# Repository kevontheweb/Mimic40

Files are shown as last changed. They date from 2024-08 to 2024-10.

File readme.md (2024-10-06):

# Mimic40

A tiny ortho board that is pretending to be a fullsize. 

> I have not ordered any pcbs yet so consider these files *under development* until i can order some to test if they work.

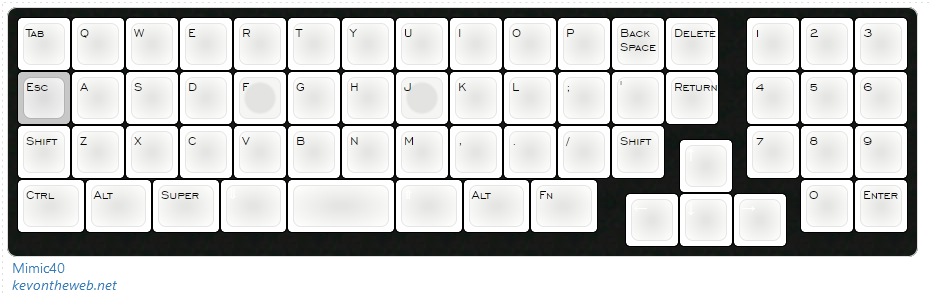
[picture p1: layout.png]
photo of the layout


<!-- ![image](https://preview.redd.it/kx884bndy0a61.jpg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) -->

## tools used to build

1. [KLE](http://www.keyboard-layout-editor.com/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'&=Return&_x:0.5%3B&=4&=5&=6%3B&@=Shift&=Z&=X&=C&=V&=B&=N&=M&=,&=.&=%2F%2F&=Shift&_x:1.5%3B&=7&=8&=9%3B&@_y:-0.75&x:12.25&t=%23ffffff%3B&=%2F&uarr%2F%3B%3B&@_y:-0.25&t=%23000000&w:1.25%3B&=Ctrl&_w:1.25%3B&=Alt&_w:1.25%3B&=Super&_t=%23ffffff&w:1.25%3B&=%2F&dArr%2F%3B&_t=%23000000&a:7&w:2%3B&=&_t=%23ffffff&a:4&w:1.25%3B&=%2F&uArr%2F%3B&_t=%23000000&w:1.25%3B&=Alt&_w:1.25%3B&=Fn&_x:3.75%3B&=0&=Enter%3B&@_y:-0.75&x:11.25&t=%23ffffff%3B&=%2F&larr%2F%3B&=%2F&darr%2F%3B&=%2F&rarr%2F)
2. [kicad](https://www.kicad.org/download/) EDA
5. [cherry mx datasheet](https://imgur.com/a/XMoHF)
<!-- x. [keyboard firmware builder](https://builder.mrkeebs.com/) for the matrix (if handwired) -->

These may be helpful for future in the design of a case

1. [builder.swillkb](builder.swillkb.com/) for the case
2. [ai03 plate generator](https://kbplate.ai03.com/)

## screenshots

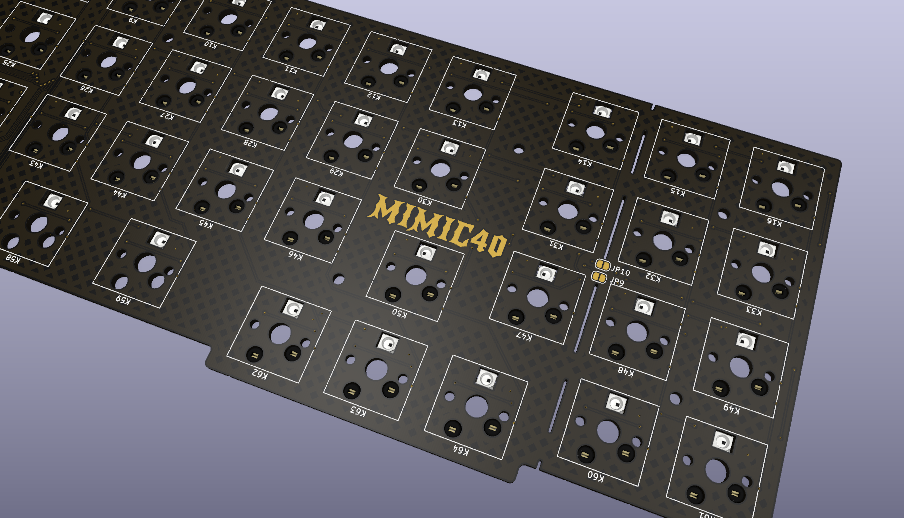
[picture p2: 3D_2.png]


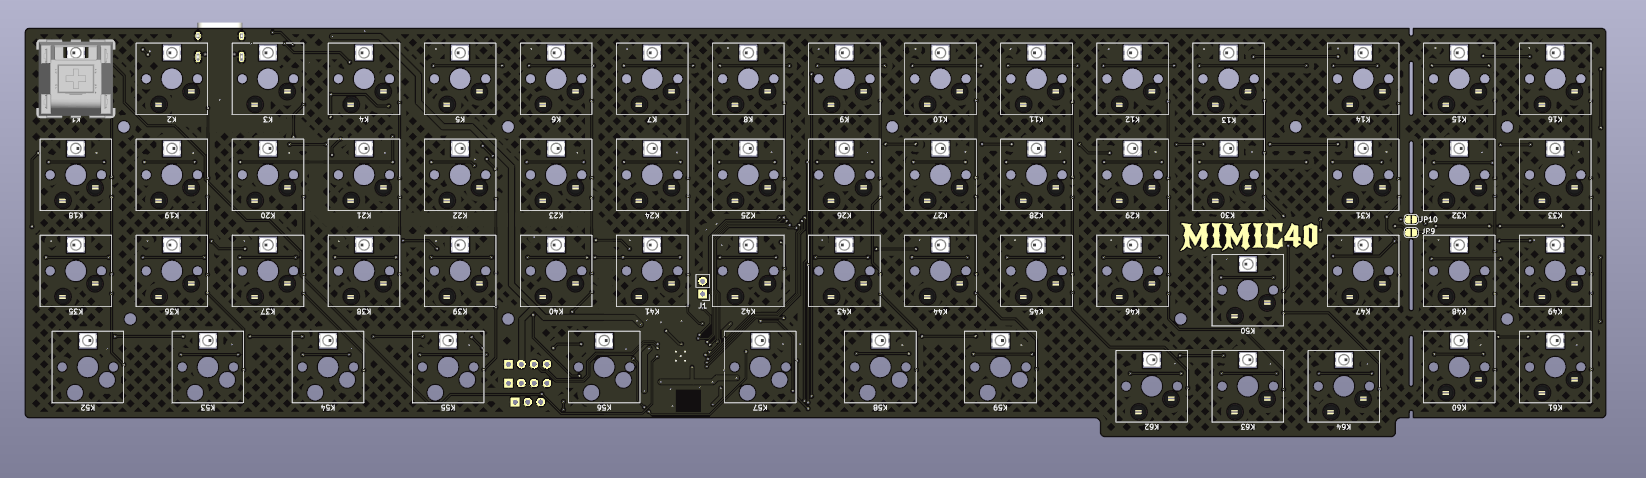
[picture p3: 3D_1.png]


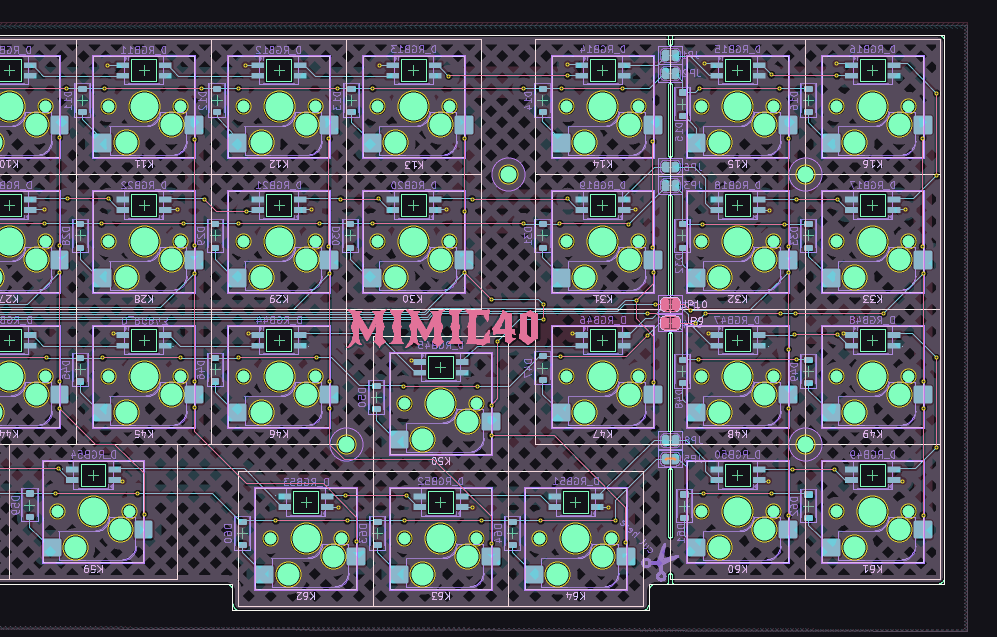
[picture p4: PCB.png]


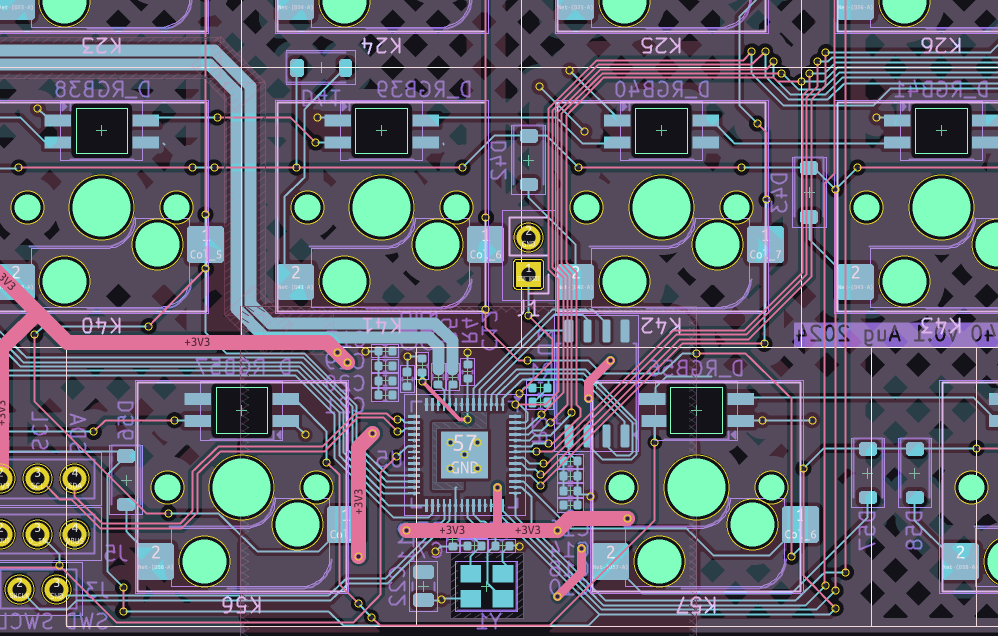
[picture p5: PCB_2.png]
photo of layout for RP2040


## references

> this was in part inspired by  [This reddit post](https://www.reddit.com/r/MechanicalKeyboards/comments/ksto32/chocolate_bar/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).

# to do

- [x] define outer geometry
- [x] per key rgb
- [x] route rows and columns
- [x] switch to rp2040 based design (no dev board)
- [x] make plate cutout file (remember to add a 2u plate mount stabiliser)
- [ ] design a case (acrlic laser cut or possible 3d printed)
- [ ] order pcbs to test
- [ ] firmware
- [ ] take it from there

## how to order

- upload gerbers
- upload bom and pos files
- confirm placements
- order missing parts elsewhere (F1 and the sockets)

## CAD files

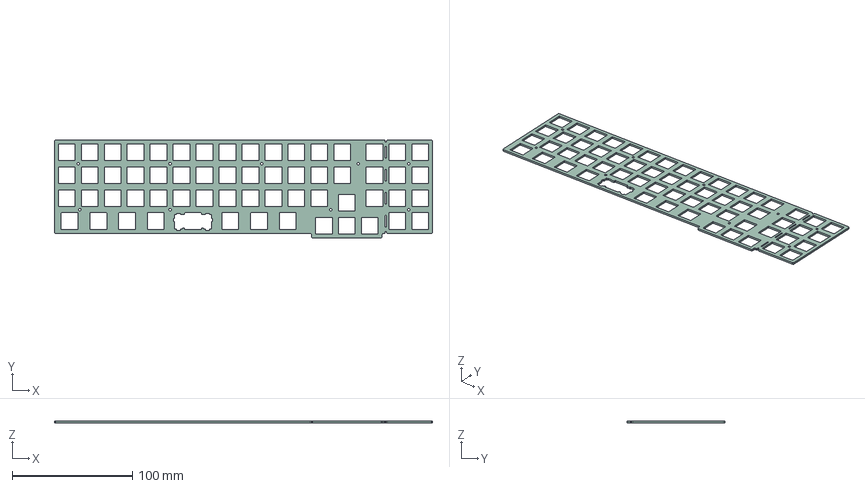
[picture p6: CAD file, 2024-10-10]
Mimic40_plate.step
313.8 x 81.2 x 1.60 mm

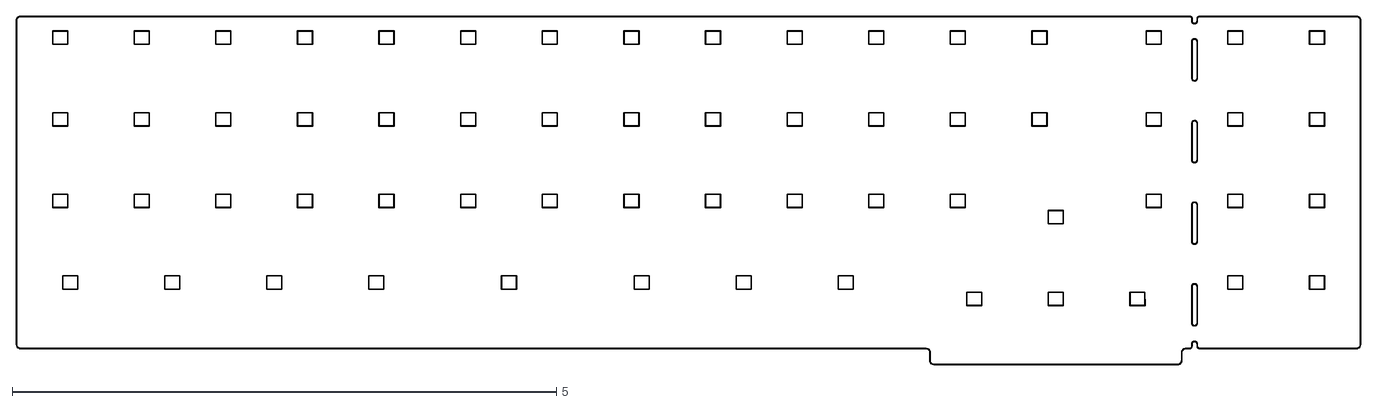
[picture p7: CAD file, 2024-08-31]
production/Mimic40_plate/Mimic40-Edge_Cuts.dxf
12.4 x 3.20

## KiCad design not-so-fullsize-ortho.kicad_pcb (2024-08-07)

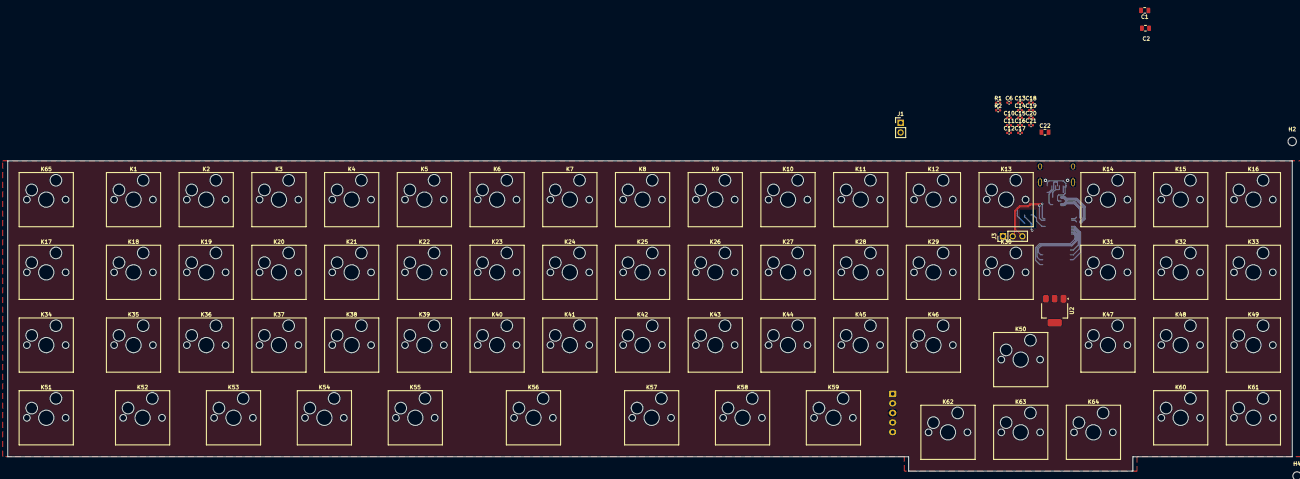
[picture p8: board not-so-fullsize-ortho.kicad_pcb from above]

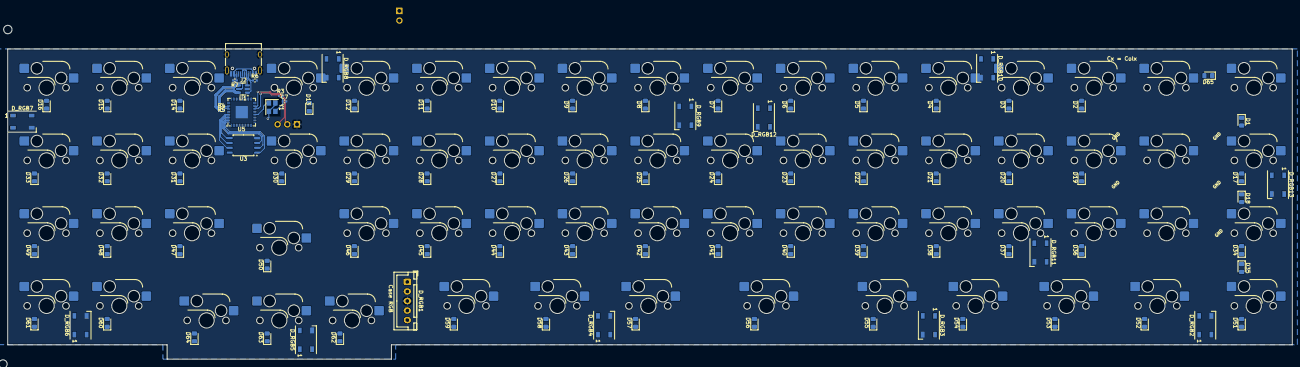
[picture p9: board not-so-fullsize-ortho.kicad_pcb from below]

Board: 2 copper layers, 336.5 x 81.2 mm, 179 parts (89 on the bottom side), 122 nets.

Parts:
C1, C2, C22: 10u; C_0805_2012Metric
C6, C7: 15p; C_0402_1005Metric
C10, C11, C12, C14, C16, C17, C18, C19, C20, C21: 100n; C_0402_1005Metric
C13, C15: 1u; C_0402_1005Metric
D1, D2, D3, D4, D5, D6, D7, D8, D9, D10, D11, D12, D13, D14, D15, D16, D17, D18, D19, D20, D21, D22, D23, D24, D25, D26, D27, D28, D29, D30, D31, D32, D33, D34, D35, D36, D37, D38, D39, D40, D41, D42, D43, D44, D45, D46, D47, D48, D49, D50, D51, D52, D53, D54, D55, D56, D57, D58, D59, D60, D61, D62, D63, D64, D65: D; D_0805_2012Metric_Pad1.15x1.40mm_HandSolder
D_RGB1: WS2812B; JST_XH_B5B-XH-A_1x05_P2.50mm_Vertical
D_RGB2, D_RGB3, D_RGB4, D_RGB5, D_RGB6, D_RGB7, D_RGB8, D_RGB9, D_RGB10, D_RGB11, D_RGB12, D_RGB13: WS2812B; LED_WS2812B_PLCC4_5.0x5.0mm_P3.2mm
H1, H2, H3, H4: MountingHole; MountingHole_2.2mm_M2
J1: Conn_01x02; PinHeader_1x02_P2.54mm_Vertical
J2: USB_C_Receptacle_USB2.0_16P; USB_C_Receptacle_HRO_TYPE-C-31-M-12
J3: Conn_01x03; PinHeader_1x03_P2.54mm_Vertical
K1: Home; SW_Hotswap_Kailh_MX_1.00u
K2: End; SW_Hotswap_Kailh_MX_1.00u
K3: Vol +; SW_Hotswap_Kailh_MX_1.00u
K4: Vol -; SW_Hotswap_Kailh_MX_1.00u
K5: Tab; SW_Hotswap_Kailh_MX_1.00u
K6: Esc; SW_Hotswap_Kailh_MX_1.00u
K7, K48: Shift; SW_Hotswap_Kailh_MX_1.00u
K8: Ctrl; SW_Hotswap_Kailh_MX_1.00u
K9: Q; SW_Hotswap_Kailh_MX_1.00u
K10: A; SW_Hotswap_Kailh_MX_1.00u
K11: Z; SW_Hotswap_Kailh_MX_1.00u
K12, K38: Alt; SW_Hotswap_Kailh_MX_1.00u
K13: W; SW_Hotswap_Kailh_MX_1.00u
K14: S; SW_Hotswap_Kailh_MX_1.00u
K15: X; SW_Hotswap_Kailh_MX_1.00u
K16: Super; SW_Hotswap_Kailh_MX_1.00u
K17: E; SW_Hotswap_Kailh_MX_1.00u
K18: D; SW_Hotswap_Kailh_MX_1.00u
K19: C; SW_Hotswap_Kailh_MX_1.00u
K20: &dArr;; SW_Hotswap_Kailh_MX_1.00u
K21: R; SW_Hotswap_Kailh_MX_1.00u
K22: F; SW_Hotswap_Kailh_MX_1.00u
K23: V; SW_Hotswap_Kailh_MX_1.00u
K24: T; SW_Hotswap_Kailh_MX_1.00u
K25: G; SW_Hotswap_Kailh_MX_1.00u
K26: B; SW_Hotswap_Kailh_MX_1.00u
K27: Blank; SW_Hotswap_Kailh_MX_1.00u
K28: Y; SW_Hotswap_Kailh_MX_1.00u
K29: H; SW_Hotswap_Kailh_MX_1.00u
K30: N; SW_Hotswap_Kailh_MX_1.00u
K31: U; SW_Hotswap_Kailh_MX_1.00u
K32: J; SW_Hotswap_Kailh_MX_1.00u
K33: M; SW_Hotswap_Kailh_MX_1.00u
K34: &uArr;; SW_Hotswap_Kailh_MX_1.00u
K35: I; SW_Hotswap_Kailh_MX_1.00u
K36: K; SW_Hotswap_Kailh_MX_1.00u
K37: ,; SW_Hotswap_Kailh_MX_1.00u
K39: O; SW_Hotswap_Kailh_MX_1.00u
K40: L; SW_Hotswap_Kailh_MX_1.00u
K41: .; SW_Hotswap_Kailh_MX_1.00u
K42: Fn; SW_Hotswap_Kailh_MX_1.00u
K43: P; SW_Hotswap_Kailh_MX_1.00u
K44: ;; SW_Hotswap_Kailh_MX_1.00u
K45: /; SW_Hotswap_Kailh_MX_1.00u
K46: Back Space; SW_Hotswap_Kailh_MX_1.00u
K47: '; SW_Hotswap_Kailh_MX_1.00u
K49: &larr;; SW_Hotswap_Kailh_MX_1.00u
K50: Delete; SW_Hotswap_Kailh_MX_1.00u
K51: Return; SW_Hotswap_Kailh_MX_1.00u
K52: &uarr;; SW_Hotswap_Kailh_MX_1.00u
K53: &darr;; SW_Hotswap_Kailh_MX_1.00u
K54: &rarr;; SW_Hotswap_Kailh_MX_1.00u
K55: 1; SW_Hotswap_Kailh_MX_1.00u
K56: 4; SW_Hotswap_Kailh_MX_1.00u
K57: 7; SW_Hotswap_Kailh_MX_1.00u
K58: 2; SW_Hotswap_Kailh_MX_1.00u
K59: 5; SW_Hotswap_Kailh_MX_1.00u
K60: 8; SW_Hotswap_Kailh_MX_1.00u
K61: 0; SW_Hotswap_Kailh_MX_1.00u
K62: 3; SW_Hotswap_Kailh_MX_1.00u
K63: 6; SW_Hotswap_Kailh_MX_1.00u
K64: 9; SW_Hotswap_Kailh_MX_1.00u
K65: Enter; SW_Hotswap_Kailh_MX_1.00u
R1, R3: 1k; R_0402_1005Metric
R2: DNF; R_0402_1005Metric
R4, R5: 27; R_0402_1005Metric
R6, R7: 5.1k; R_0402_1005Metric
U1: USBLC6-2SC6; SOT-23-6
U2: NCP1117-3.3_SOT223; SOT-223-3_TabPin2
U3: W25Q128JVS; SOIC-8_5.23x5.23mm_P1.27mm
U5: RP2040; QFN-56-1EP_7x7mm_P0.4mm_EP3.2x3.2mm
Y1: ABM8-272-T3; Crystal_SMD_3225-4Pin_3.2x2.5mm

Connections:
+1V1: C11.1, C12.1, C13.1, U5.23 (DVDD), U5.45 (VREG_VOUT), U5.50 (DVDD)
+3V3: C2.1, C10.1, C14.1, C15.1, C16.1, C17.1, C18.1, C19.1, C20.1, C21.1, C22.1, R2.1, U2.2 (VO), U3.8 (VCC), U5.1 (IOVDD), U5.10 (IOVDD), U5.22 (IOVDD), U5.33 (IOVDD), U5.42 (IOVDD), U5.43 (ADC_AVDD), U5.44 (VREG_IN), U5.48 (USB_VDD), U5.49 (IOVDD)
/Col_0: K1.1, K2.1, K3.1, K4.1, U5.2 (GPIO0)
/Col_1: K5.1, K6.1, K7.1, K8.1, U5.3 (GPIO1)
/Col_2: K9.1, K10.1, K11.1, K12.1, U5.4 (GPIO2)
/Col_3: K13.1, K14.1, K15.1, U5.18 (GPIO15)
/Col_4: K16.1, K17.1, K18.1, K19.1, U5.17 (GPIO14)
/Col_5: K20.1, K21.1, K22.1, K23.1, U5.15 (GPIO12)
/Col_6: K24.1, K25.1, K26.1, K27.1, U5.14 (GPIO11)
/Col_7: K28.1, K29.1, K30.1, U5.13 (GPIO10)
/Col_8: K31.1, K32.1, K33.1, K34.1, U5.12 (GPIO9)
/Col_9: K35.1, K36.1, K37.1, K38.1, U5.11 (GPIO8)
/Col_10: K39.1, K40.1, K41.1, K42.1, U5.9 (GPIO7)
/Col_11: K43.1, K44.1, K45.1, U5.8 (GPIO6)
/Col_12: K46.1, K47.1, K48.1, K49.1, U5.7 (GPIO5)
/Col_13: K50.1, K51.1, K52.1, K53.1, U5.16 (GPIO13)
/Col_14: K54.1, K55.1, K56.1, K57.1, U5.6 (GPIO4)
/Col_15: K58.1, K59.1, K60.1, K61.1, U5.5 (GPIO3)
/Col_16: K62.1, K63.1, K64.1, K65.1, U5.27 (GPIO16)
/RP2040/QSPI_SCLK: U3.6 (CLK), U5.52 (QSPI_SCLK)
/RP2040/QSPI_SD0: U3.5 (DI(IO0)), U5.53 (QSPI_SD0)
/RP2040/QSPI_SD1: U3.2 (DO(IO1)), U5.55 (QSPI_SD1)
/RP2040/QSPI_SD2: U3.3 (IO2), U5.54 (QSPI_SD2)
/RP2040/QSPI_SD3: U3.7 (IO3), U5.51 (QSPI_SD3)
/RP2040/QSPI_SS: R1.1, R2.2, U3.1 (~CS), U5.56 (QSPI_SS)
/RP2040/XIN: C6.1, U5.20 (XIN), Y1.1
/RP2040/XOUT: R3.1, U5.21 (XOUT)
/RP2040/~USB_BOOT: J1.1, R1.2
/Row_0: D1.1 (K), D5.1 (K), D9.1 (K), D13.1 (K), D17.1 (K), D21.1 (K), D24.1 (K), D28.1 (K), D31.1 (K), D35.1 (K), D39.1 (K), D43.1 (K), D46.1 (K), D50.1 (K), D55.1 (K), D58.1 (K), D62.1 (K), U5.32 (GPIO21)
/Row_1: D2.1 (K), D6.1 (K), D10.1 (K), D14.1 (K), D18.1 (K), D22.1 (K), D25.1 (K), D29.1 (K), D32.1 (K), D36.1 (K), D40.1 (K), D44.1 (K), D47.1 (K), D51.1 (K), D56.1 (K), D59.1 (K), D63.1 (K), U5.31 (GPIO20)
/Row_2: D3.1 (K), D7.1 (K), D11.1 (K), D15.1 (K), D19.1 (K), D23.1 (K), D26.1 (K), D30.1 (K), D33.1 (K), D37.1 (K), D41.1 (K), D45.1 (K), D48.1 (K), D52.1 (K), D57.1 (K), D60.1 (K), D64.1 (K), U5.30 (GPIO19)
/Row_3: D4.1 (K), D8.1 (K), D12.1 (K), D16.1 (K), D20.1 (K), D27.1 (K), D34.1 (K), D38.1 (K), D42.1 (K), D49.1 (K), D53.1 (K), D54.1 (K), D61.1 (K), D65.1 (K), U5.29 (GPIO18)
/SWCLK: J3.3, U5.24 (SWCLK)
/SWD: J3.2, U5.25 (SWD)
/USB/D+: J2.A6 (D+), J2.B6 (D+), U1.3 (I/O2)
/USB/D-: J2.A7 (D-), J2.B7 (D-), U1.1 (I/O1)
/USB_D+: R4.1, U1.4 (I/O2)
/USB_D-: R5.2, U1.6 (I/O1)
GND: C1.2, C2.2, C6.2, C7.2, C10.2, C11.2, C12.2, C13.2, C14.2, C15.2, C16.2, C17.2, C18.2, C19.2, C20.2, C21.2, C22.2, D_RGB1.3 (VSS), D_RGB2.3 (VSS), D_RGB3.3 (VSS), D_RGB4.3 (VSS), D_RGB5.3 (VSS), D_RGB6.3 (VSS), D_RGB7.3 (VSS), D_RGB8.3 (VSS), D_RGB9.3 (VSS), D_RGB10.3 (VSS), D_RGB11.3 (VSS), D_RGB12.3 (VSS), D_RGB13.3 (VSS), J1.2, J2.A1 (GND), J2.A12 (GND), J2.B1 (GND), J2.B12 (GND), J2.S1 (SHIELD), J3.1, R6.2, R7.2, U1.2 (GND), U2.1 (GND), U3.4 (GND), U5.57 (GND), Y1.2, Y1.4
unnamed: C7.1, R3.2, Y1.3
unnamed: D1.2 (A), K1.2
unnamed: D2.2 (A), K2.2
unnamed: D3.2 (A), K3.2
unnamed: D4.2 (A), K4.2
unnamed: D5.2 (A), K5.2
unnamed: D6.2 (A), K6.2
unnamed: D7.2 (A), K7.2
unnamed: D8.2 (A), K8.2
unnamed: D9.2 (A), K9.2
unnamed: D10.2 (A), K10.2
unnamed: D11.2 (A), K11.2
unnamed: D12.2 (A), K12.2
unnamed: D13.2 (A), K13.2
unnamed: D14.2 (A), K14.2
unnamed: D15.2 (A), K15.2
unnamed: D16.2 (A), K16.2
unnamed: D17.2 (A), K17.2
unnamed: D18.2 (A), K18.2
unnamed: D19.2 (A), K19.2
unnamed: D20.2 (A), K20.2
unnamed: D21.2 (A), K21.2
unnamed: D22.2 (A), K22.2
unnamed: D23.2 (A), K23.2
unnamed: D24.2 (A), K24.2
unnamed: D25.2 (A), K25.2
unnamed: D26.2 (A), K26.2
unnamed: D27.2 (A), K27.2
unnamed: D28.2 (A), K28.2
unnamed: D29.2 (A), K29.2
unnamed: D30.2 (A), K30.2
unnamed: D31.2 (A), K31.2
unnamed: D32.2 (A), K32.2
unnamed: D33.2 (A), K33.2
unnamed: D34.2 (A), K34.2
unnamed: D35.2 (A), K35.2
unnamed: D36.2 (A), K36.2
unnamed: D37.2 (A), K37.2
unnamed: D38.2 (A), K38.2
unnamed: D39.2 (A), K39.2
unnamed: D40.2 (A), K40.2
unnamed: D41.2 (A), K41.2
unnamed: D42.2 (A), K42.2
unnamed: D43.2 (A), K43.2
unnamed: D44.2 (A), K44.2
unnamed: D45.2 (A), K45.2
unnamed: D46.2 (A), K46.2
unnamed: D47.2 (A), K47.2
unnamed: D48.2 (A), K48.2
unnamed: D49.2 (A), K49.2
unnamed: D50.2 (A), K50.2
unnamed: D51.2 (A), K51.2
unnamed: D52.2 (A), K52.2
unnamed: D53.2 (A), K53.2
unnamed: D54.2 (A), K54.2
unnamed: D55.2 (A), K55.2
unnamed: D56.2 (A), K56.2
unnamed: D57.2 (A), K57.2
unnamed: D58.2 (A), K58.2
unnamed: D59.2 (A), K59.2
unnamed: D60.2 (A), K60.2
unnamed: D61.2 (A), K61.2
unnamed: D62.2 (A), K62.2
unnamed: D63.2 (A), K63.2
unnamed: D64.2 (A), K64.2
unnamed: D65.2 (A), K65.2
unnamed: D_RGB1.2 (DOUT), D_RGB4.4 (DIN)
unnamed: D_RGB2.2 (DOUT), D_RGB5.4 (DIN)
unnamed: D_RGB3.2 (DOUT), D_RGB6.4 (DIN)
unnamed: D_RGB4.2 (DOUT), D_RGB7.4 (DIN)
unnamed: D_RGB6.2 (DOUT), D_RGB8.4 (DIN)
unnamed: D_RGB7.2 (DOUT), D_RGB9.4 (DIN)
unnamed: D_RGB8.2 (DOUT), D_RGB10.4 (DIN)
unnamed: D_RGB10.2 (DOUT), D_RGB12.4 (DIN)
unnamed: D_RGB9.2 (DOUT), D_RGB11.4 (DIN)
unnamed: D_RGB11.2 (DOUT), D_RGB13.4 (DIN)
unnamed: D_RGB2.4 (DIN), D_RGB12.2 (DOUT)
unnamed: D_RGB3.4 (DIN), D_RGB13.2 (DOUT)
unnamed: J2.A5 (CC1), R6.1
unnamed: J2.B5 (CC2), R7.1
unnamed: R5.1, U5.46 (USB_DM)
unnamed: R4.2, U5.47 (USB_DP)
VBUS: C1.1, D_RGB1.1 (VDD), D_RGB2.1 (VDD), D_RGB3.1 (VDD), D_RGB4.1 (VDD), D_RGB5.1 (VDD), D_RGB6.1 (VDD), D_RGB7.1 (VDD), D_RGB8.1 (VDD), D_RGB9.1 (VDD), D_RGB10.1 (VDD), D_RGB11.1 (VDD), D_RGB12.1 (VDD), D_RGB13.1 (VDD), J2.A4 (VBUS), J2.A9 (VBUS), J2.B4 (VBUS), J2.B9 (VBUS), U1.5 (VBUS), U2.3 (VI)

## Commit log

2023-02-14 add production files (gerbers and such) for JLC PCB
    [bom.csv, designators.csv, positions.csv]
2024-08-07 rework for rp2040 (not pico dev board)
    kicad 8 version bump, much better schematic, some DRC rules, start with layout of rp2040/USB portion of board, will need to reroute all the rows/cols when done.
    [LEDs.kicad_sch, RP2040.kicad_sch, SwitchMatrix.kicad_sch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]
2024-08-08 layout rp2040 mwe
    [RP2040.kicad_sch, SwitchMatrix.kicad_sch, not-so-fullsize-ortho.kicad_sch]
2024-08-11 per key rgb (reverse mount sk6812 mini e, geometry finalisation
    [LEDs.kicad_sch, USB.kicad_sch]
2024-08-12 remove left most column, reroute rp2040
    remove left most column, reroute rp2040 to fit in-between switches, no more oled, last 2 cols (right) are snap off.
    still to do:
    - check that the snap cutouts aren't too much,
    - add mounting holes for if the side is snapped off.
    - still to route columns/rows
    [LEDs.kicad_sch, SwitchMatrix.kicad_sch, not-so-fullsize-ortho.kicad_sch]
2024-08-17 routing, rotate leds to make tracks easier
    [LEDs.kicad_sch, RP2040.kicad_sch, SwitchMatrix.kicad_sch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]
2024-08-18 pretty much done
    [LEDs.kicad_sch, SwitchMatrix.kicad_sch, not-so-fullsize-ortho-Edge_Cuts.dxf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]
2024-08-19 test prod files for jlc quote, wrong diode footprint 🤦‍
    [LEDs.kicad_sch, SwitchMatrix.kicad_sch, bom.csv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]
2024-08-22 sod-128 diodes, still wrong it was supposed to be 123
    [SwitchMatrix.kicad_sch]
2024-08-22 rename, pcbway prod
    [Edge_Cuts.dxf, Mimic40.kicad_sch, bom.csv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]
2024-08-22 prod files, fix silkscreens
    [Mimic40-B_Adhesive.gbr, Mimic40-B_Cu.gbr, Mimic40-B_Mask.gbr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]
2024-08-22 last before prod
    [Sample_BOM_PCBWay.xlsx, SwitchMatrix.kicad_sch]
2024-08-26 plate + usb soldermask fix
    [Mimic40-B_Adhesive.gbr, Mimic40-B_Cu.gbr, Mimic40-B_Mask.gbr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]
2024-08-26 pcbway bom
    [bom.xlsx]
2024-08-26 add part nums for bom
    [LEDs.kicad_sch, Mimic40.kicad_sch, RP2040.kicad_sch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]
2024-08-26 finishing touches b4 prod
    [Edge_Cuts.dxf, Mimic40-BoM.xlsx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]
2024-08-31 cleanup, fix soldermask expansion and silkscreens, boms for jlc and pcbway
    [Mimic40-BoM.xlsx, Mimic40-Edge_Cuts.dxf, Mimic40-bom-pcbway.xlsx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]
2024-08-31 udpate plate
    [Mimic40-Edge_Cuts.dxf, Mimic40_plate.kicad_pcb]
2024-09-22 usb changes for high power (leds)
    [LEDs.kicad_sch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]
2024-10-06 bulk cap and level shifter (still need to lay out)
    [LEDs.kicad_sch, Level Shifter.kicad_sch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]
2024-10-08 bulk caps for power (todo, split 470uF cap so that it can be shorter)
    [LEDs.kicad_sch, Level Shifter.kicad_sch, Mimic40.kicad_sch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]
2024-10-10 add debug led, make bulk caps smaller, export plate and bottom for rudimentary case
    [LEDs.kicad_sch, Level Shifter.kicad_sch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]
2024-10-12 enlarge mounting holes, custom rules
    [LEDs.kicad_sch, SwitchMatrix.kicad_sch, USB.kicad_sch]
2024-10-19 fab output changes (part choice updates)
    [LEDs.kicad_sch, Level Shifter.kicad_sch, Mimic40.kicad_sch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]
2024-11-12 switch to solderable sockets, you can millmax if you want.
    [LEDs.kicad_sch, Level Shifter.kicad_sch, Mimic40.kicad_sch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]
